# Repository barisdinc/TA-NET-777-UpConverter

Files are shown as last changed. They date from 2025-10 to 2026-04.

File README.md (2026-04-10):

# TA-NET-777-UpConverter
Bu proje yeniden ATOLYE grubu tarafindan TA-NET 777 katilimcilari icin hazirlanmis bir 2.4 GHz Upconverter projesidir.
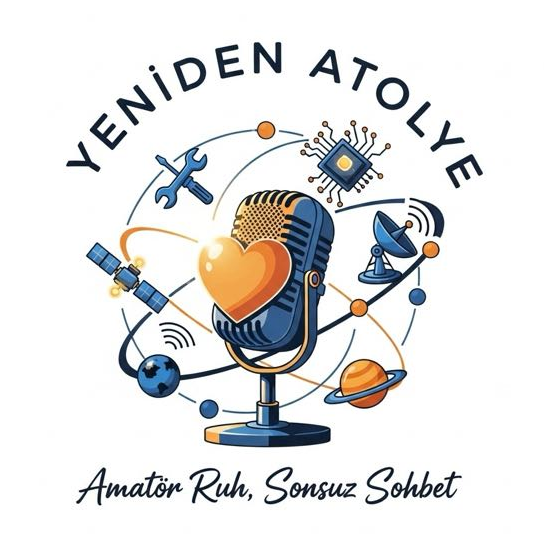
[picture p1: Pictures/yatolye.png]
yenidenATOLYE

Proje hakkinda detayli bilgiler icin asagidaki video ve sunumu izlemenizi oneririz :
- https://youtu.be/WVTPuhvnB4w
- https://youtu.be/KhWMfrUOU8w
- https://youtu.be/caV9FkoR3bo
- https://youtu.be/nuQJzcfvQ-c

Playlist 
- https://www.youtube.com/playlist?list=PLecaGE98mtkhjbvLQakkzYl7DVgV7Ta73

Genel Ozellikleri :
- HF/VHF/UHF cihazlari kullanarak (SSB) QO-100 uyudusuna upconvert yapmak icin kullanilir
- 28/50/144/435 MHz girisinden 2.4 GHz'e upconvert islemini yapar.
- secimi uzerinde bulunan 2 adet dipswitch ile yapilmaktadir
- 28 Mhz yerine opsiyonel olarak 1200 MHz kullanabilrisiniz, kod icinde gerekli duzenlemeler ile ilgili aciklamalar mevcuttur
- Maksimum giris gucu 5 Watt i asmamalidir
- cihazin cikis gucu (SKY ile ) 1 watt civasindandir ve EDUP benzeri anfiler ile daha yuksek guclere cikilabilir
- SKY kullanilmadigi durumda 100-200 Miliwat civarinda bir guc ile istediginiz bir anfi ile kullanabilirisiniz

- Konu hakkinda detayli bir yaziyi da asagidaki sayfada bulabilirsiniz :

https://ta1d.com/qo100-up-converter-ta777-yeni-atolye-grup-calismasi/

Sema, GERBER ve PCB detaylarini (ve BOM ) bilgilerini dokumanlar dizininde bulabilirsiniz.
Kodu nasil derleyeceginiz (arduinino ya da avr-gcc ile) kodun bas kisminda mevcuttur.
Hazir derlenmis HEX dosyalari da yukaridaki klasorlerde mevcuttur

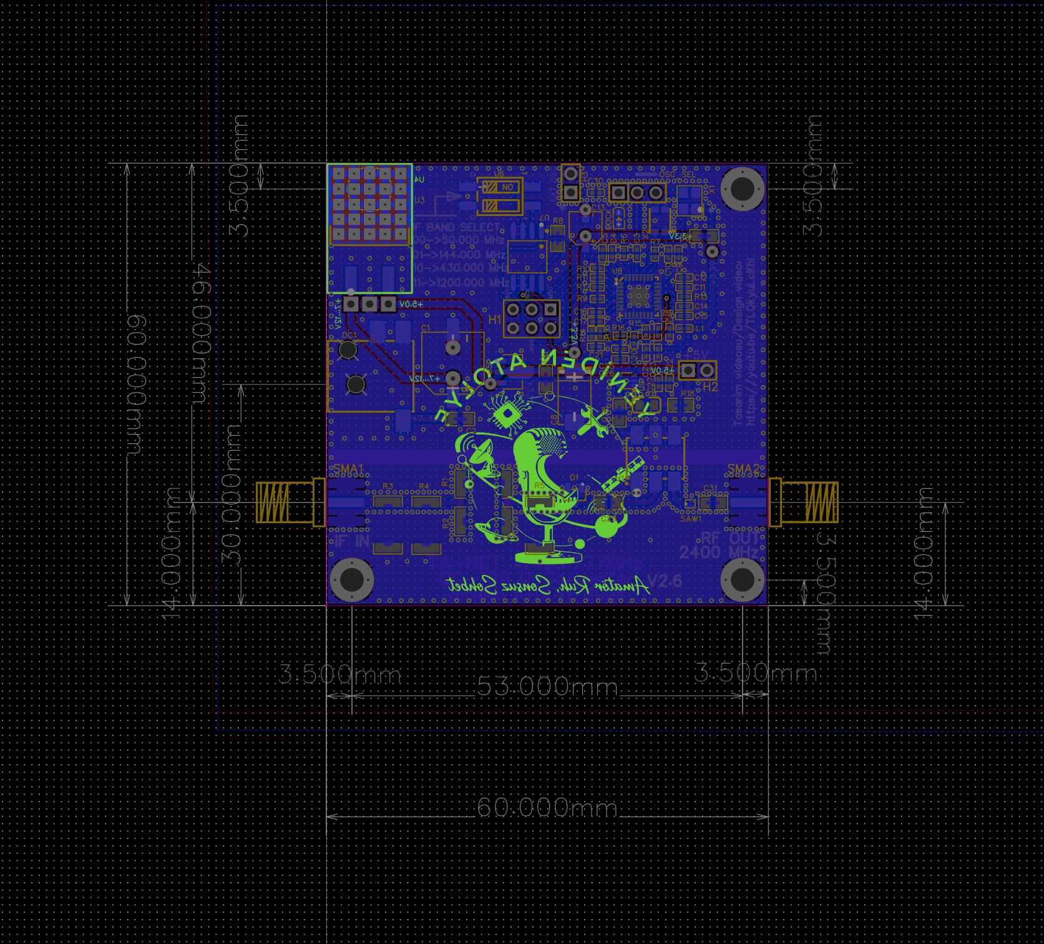
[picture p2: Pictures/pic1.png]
sizes

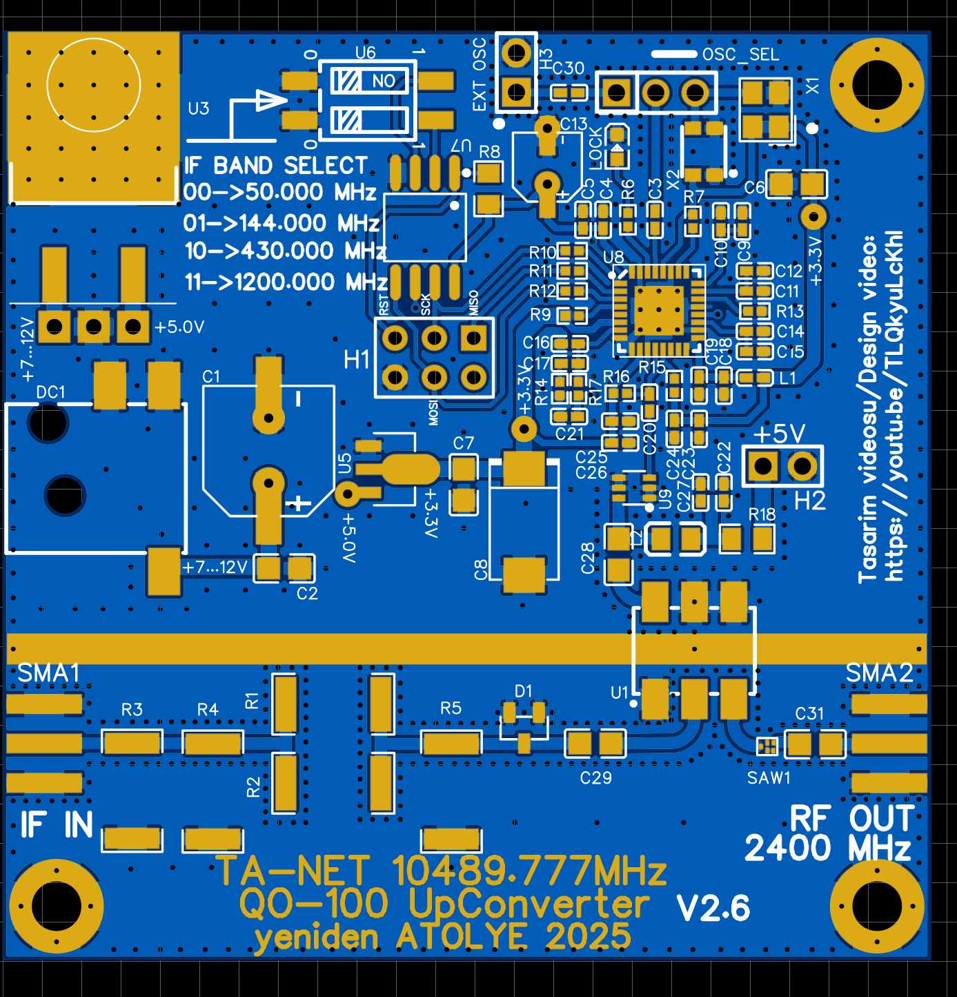
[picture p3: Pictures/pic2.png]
2D View

2D Gorunum
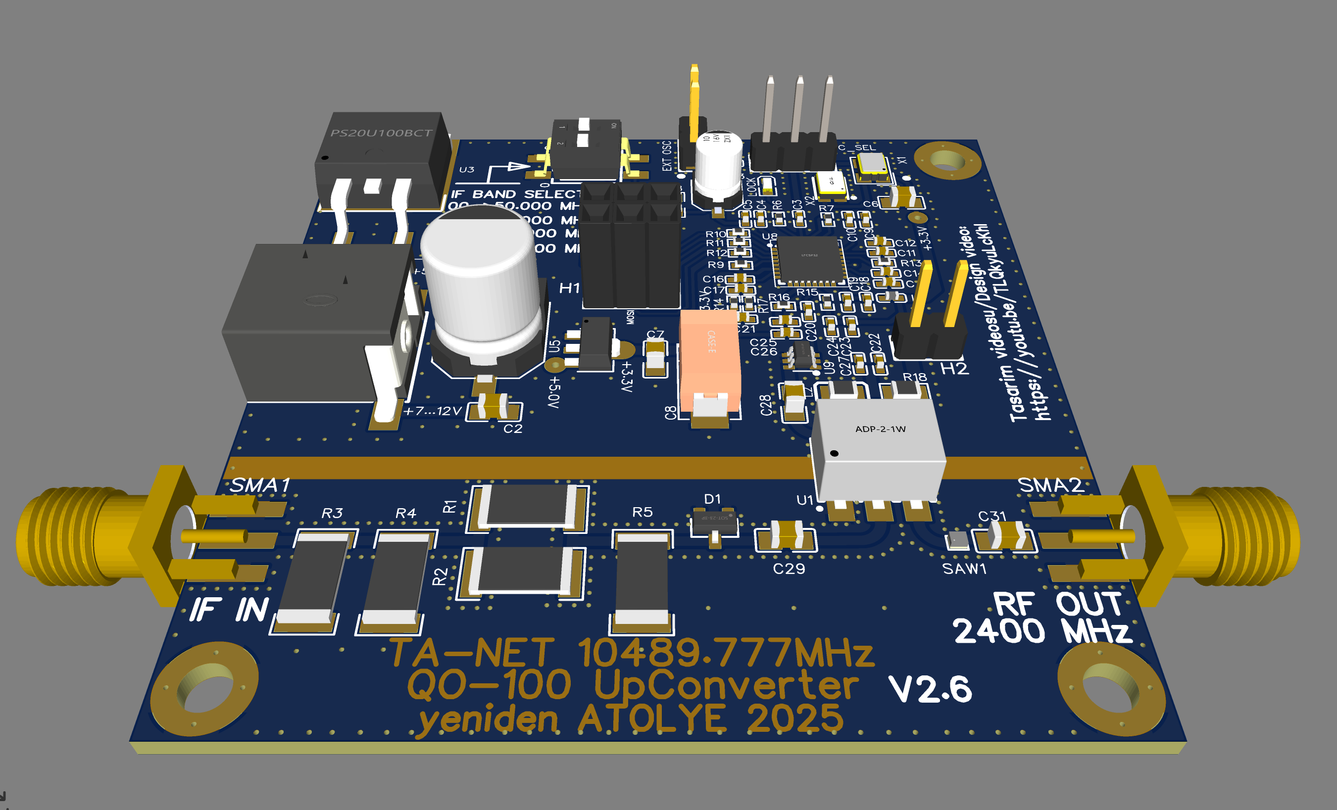
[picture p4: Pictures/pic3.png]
3D View - Front

3D Gorunum (On)
3D View Back
3D Gorunum (arka)
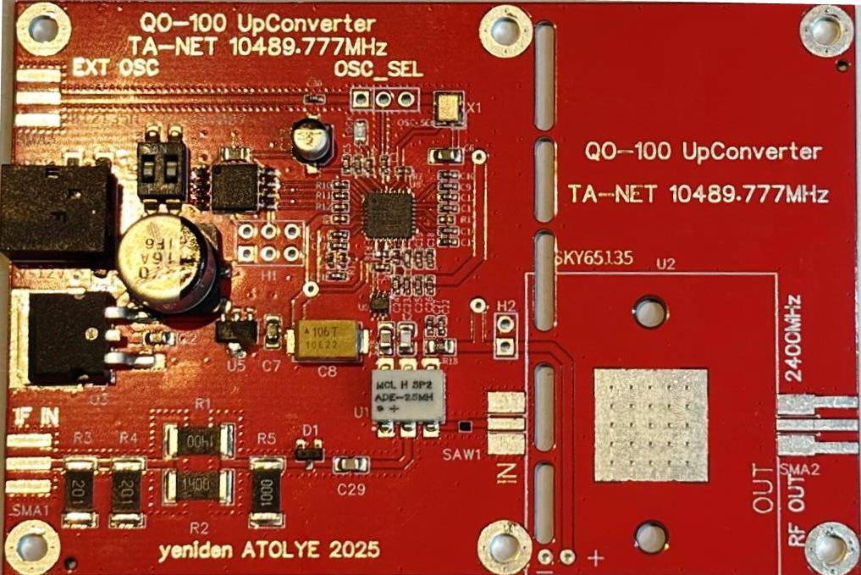
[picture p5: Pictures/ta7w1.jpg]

Prototip Gorunumu 1
Prototypes
Prototip Gorunumu 2
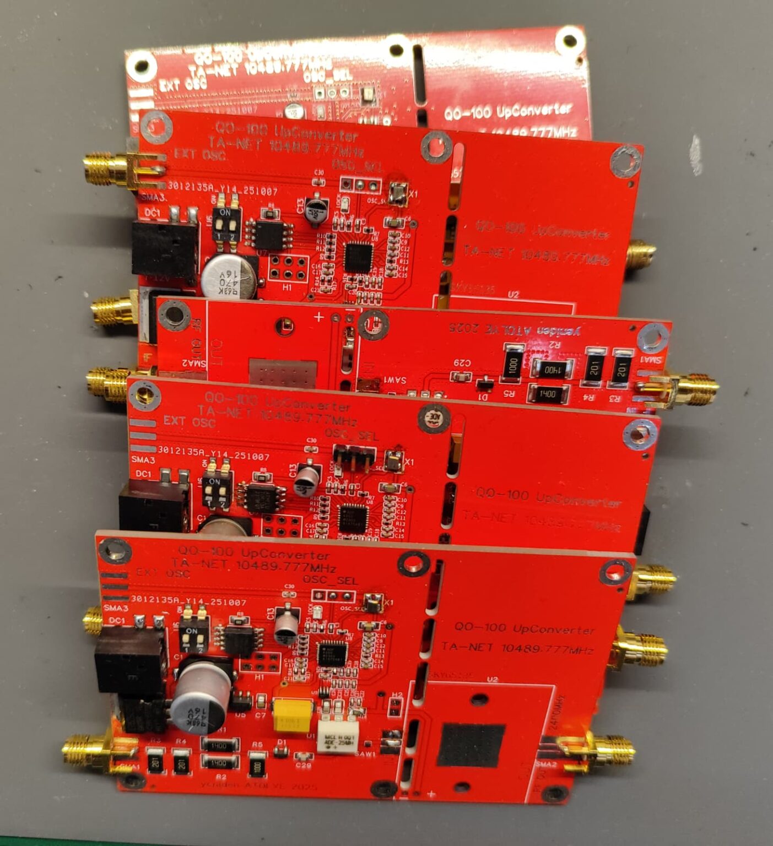
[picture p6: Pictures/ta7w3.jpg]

Prototip Gorunumu 3
Prototypes
Prototip Gorunumu 4
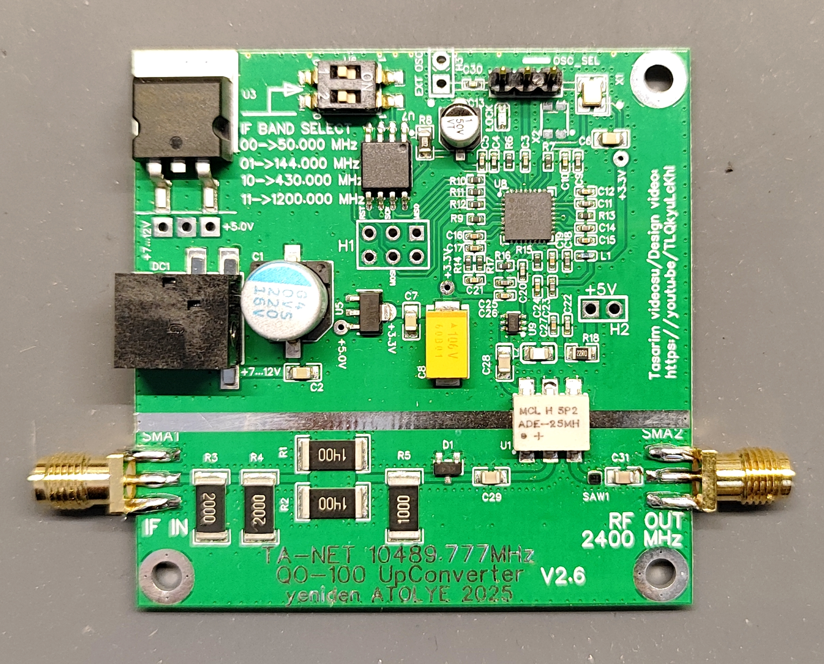
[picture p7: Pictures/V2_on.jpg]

V2 Versiyon On Yuz
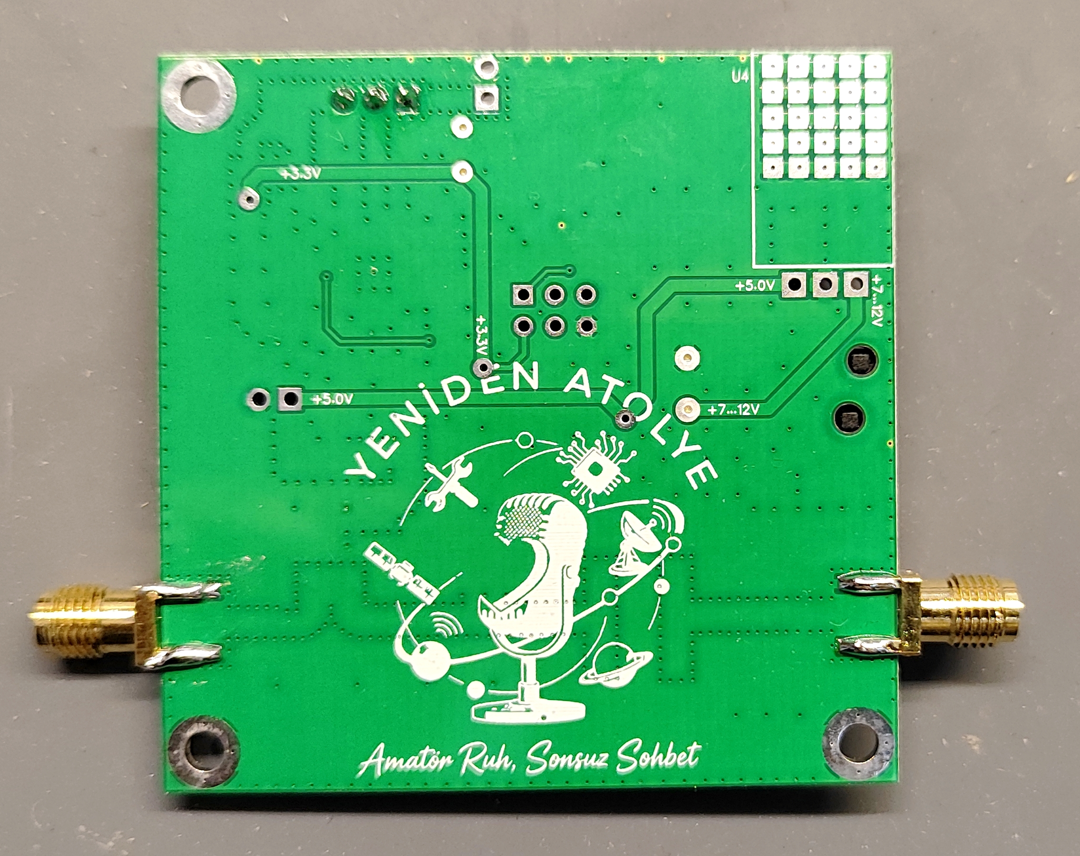
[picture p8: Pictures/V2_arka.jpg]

V2 Versiyon Arka Yuz
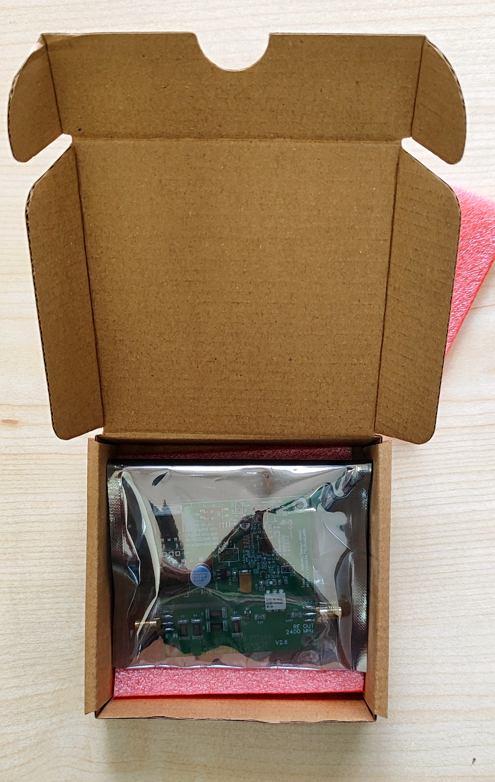
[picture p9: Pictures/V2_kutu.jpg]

V2 Versiyon Kutulanmis

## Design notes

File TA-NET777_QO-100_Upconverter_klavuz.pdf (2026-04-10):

# ATÖLYE ÇALIŞMA GRUBU

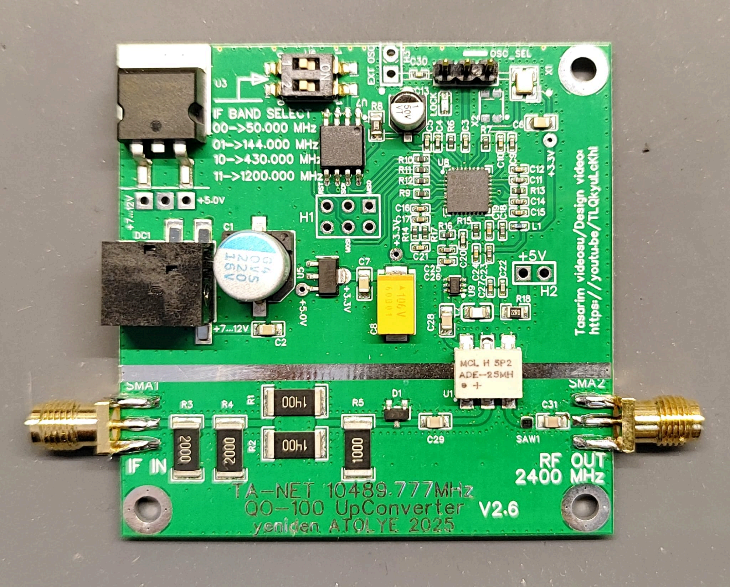
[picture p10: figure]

# QO-100 / 2400 MHz UpConverter Kiti

# Açıklama Dokümanı

# Projenin Amacı

Atölye grubu radyo amatörlüğü konularında araştırma ve geliştirme faaliyetleri gösteren küçük

bir amatör topluluktur. Grup, elektronik ve teknik konularda araştırma faaliyetlerini videolar,

dokümanlar, çalışma grupları ve hazırladıkları kitler aracılığı ile diğer radyo amatörleri ile de

paylaşmayı hedeflemiştir.

Atölye çalışma grubu tarafından tasarlanan ve imal edilen “TA-NET 777 QO-100 Upconverter”

devresinin amacı, öncelikle ülkemizdeki QO-100 uydusu kullanımını yaygınlaştırmak ve SHF

(Super High Frequency) yüksek frekans kullanımı konusunda kullanıcı farkındalığını arttırarak

mikrodalga haberleşmesine olan ilgiyi arttırmaktır.

Bu kapsamda 2025 yılı faaliyetleri kapsamında aşağıda detayları açıklanan HF, VHF, UHF ve

SHF frekanslarından (28MHz, 145MHz, 435MHz ve 1250 MHz) özellikle QO-100 uydusunun

uplink frekansı olarak kullanılan 13cm (2400 MHz) bandına yükseltilmesini sağlayacak bir proje

gerçekleştirilmiş, projenin tasarım çalışmaları ve konu ile ilgili anlatımlı sunumlar

https://www.youtube.com/playlist?list=PLecaGE98mtkhjbvLQakkzYl7DVgV7Ta73 Adresinde

bulunan youtube videosu ile paylaşılmıştır.

# Upconverter için nasıl bir sisteme sahip olmalıyım ?

Upconverter kullanabilmek için, elinizde giriş frekanslarından herhangi birinde çalışan bir SSB

telsiz ihtiyacınız vardır, örneğin :

- VHF SSB (ICOM IC-705, ICOM IC-706, YAESU FT-817, YAESU FT857, vb.)
- UHF SSB (ICOM IC-705, ICOM IC-706, YAESU FT-817, YAESU FT857, vb.)
- SHF SSB (ICOM IC-9700, KENWOOD TS-2000X, vb.)
- 50 MHz (ICOM HF, YAESU HF cihazlar ve QMX+ )

# Sistemin genel blok şeması nasıldır ?

Anten bileşeni dahil sistemin alt bileşenlerinin gösterildiği blok şema yapısı aşağıdaki gibidir :

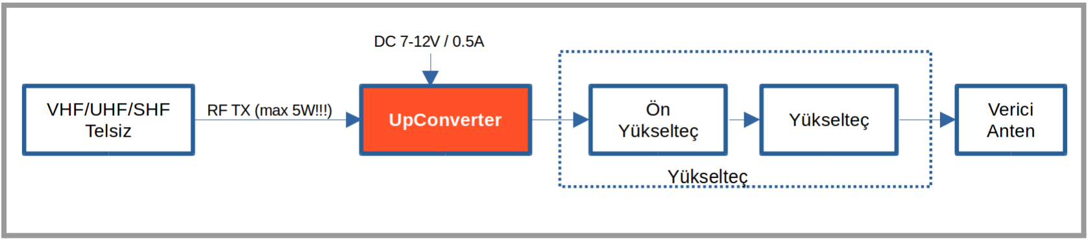
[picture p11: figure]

Şekil 1 - Sistemin Blok Şeması

# Sistemin detay şeması

Sistemin elektronik şema çizimi aşağıdaki gibidir. Bu şema EasyEda yazılımı kullanılarak

hazırlanmış olup, hazırlanma aşaması ve bu aşamada verilen tüm kararar yukarıda paylaşılan

video linkinde bulunan videolardan detaylıca takip edilebilir. Her kullanıcı olmasa da radyo

amatörlüğünün teknik ve elektronik alanına ilgi duyanların bu videoları izleyerek farklı frekanslar

için tasarlanabilecek updonverter/downconverter çalışmalarına destek olacağını düşünüyoruz.

Videolarda sadece bir upconverter/downconverter tasarımı konusu değil temel elektronik

tasarımı esnasında izlenen adımlar detaylıca anlatılmaya çalışılmış ve bu çalışmanın bir eğitim

içeriği olmasına özen gösterilmeye çalışılmıştır.

Şema 2 bölümden oluşmaktadır :

- Üst seviye şematik
- Osilatör ve Mixer

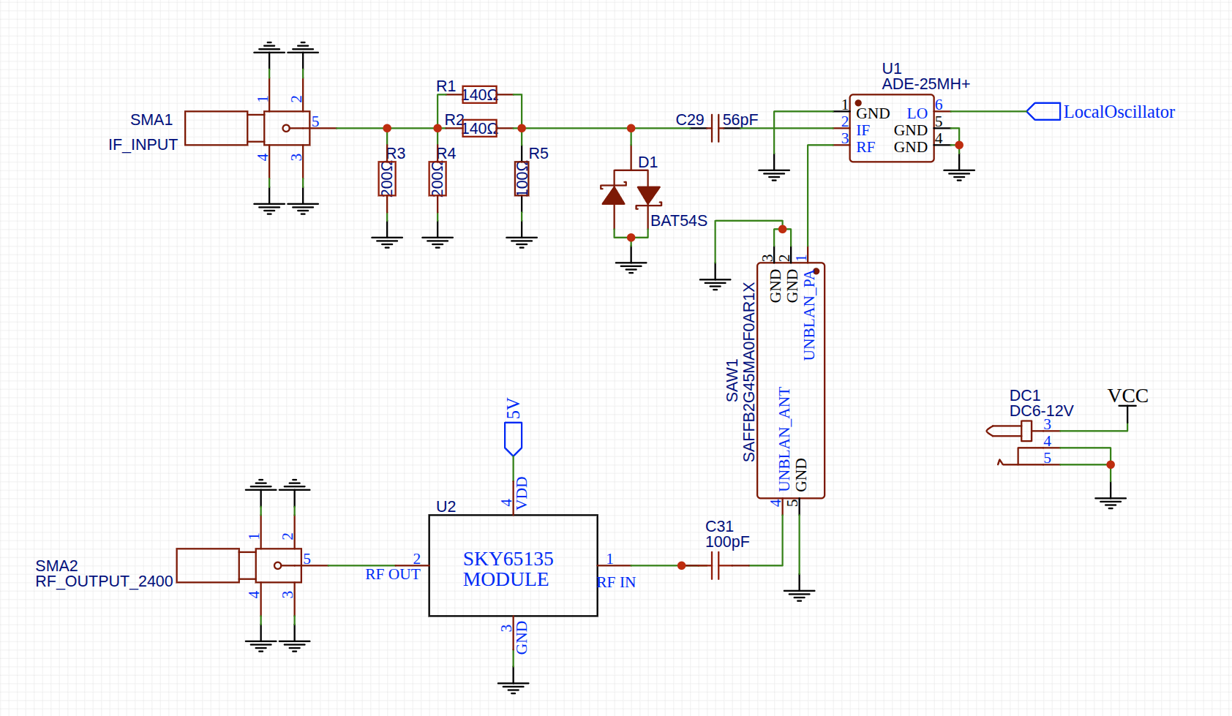
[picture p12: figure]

Şekil 2 - Üst Seviye Şematik

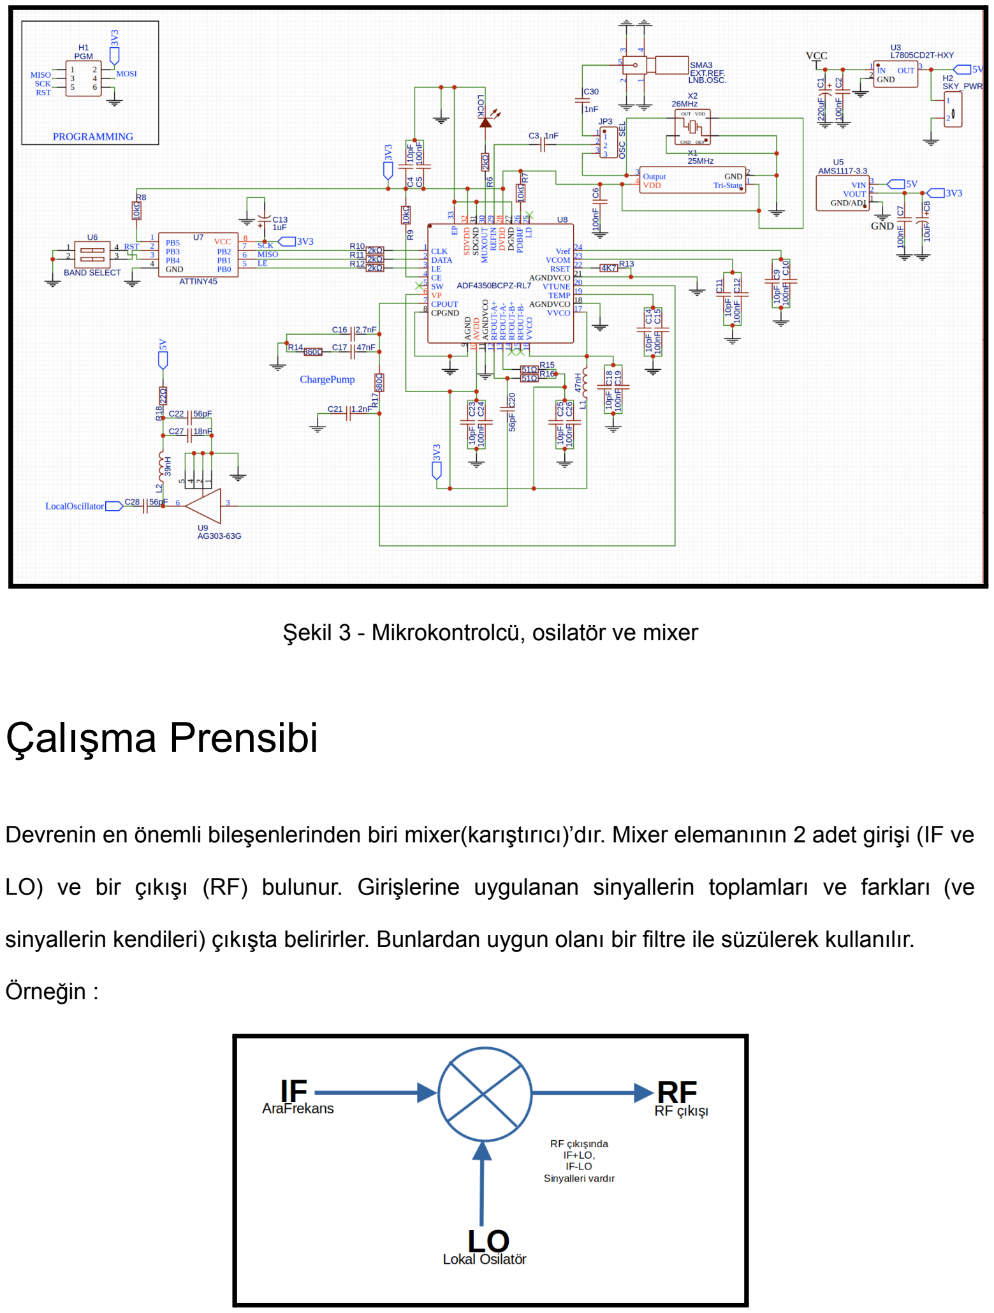
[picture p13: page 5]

Şekil 3 - Mikrokontrolcü, osilatör ve mixer

# Çalışma Prensibi

Devrenin en önemli bileşenlerinden biri mixer(karıştırıcı)’dır. Mixer elemanının 2 adet girişi (IF ve

LO) ve bir çıkışı (RF) bulunur. Girişlerine uygulanan sinyallerin toplamları ve farkları (ve

sinyallerin kendileri) çıkışta belirirler. Bunlardan uygun olanı bir filtre ile süzülerek kullanılır.

Örneğin :

Devrede ATTiny mikroişlemcisi tarafından yönetilen ADF4350/ADF4351 frekans sentözörü Lokal

Osilatör sinyali olarak kullanılak olan RF sinyalini üretir.

Bu frekans kullanılacak IF telsiz girişi frekansı ile uygun olarak aşağıdaki frekansları

üretmektedir;

- VHF telsiz için 2400 - 145 = 2255MHz
- UHF Telsiz için 2400 - 435 = 1965 Mhz
- 50 Mhz bandı için 2400 - 50 = 2350 MHz
- 1250 MHz için 2400 - 1250 = 1150 MHz

Böylece telsizden gelen sinyal ile lokal osilatörde üretilen sinyal kullanılan ADE-25MH

mikserinde karıştırıldığında çıkışında 2400 Mhz oluşur. Bu sinyal diğer bileşenlerden kurtulmak

için bir filtre ile temizlenir.

# Devre üzerindeki malzeme listesi

Devre üzerinde yer alan malzemelerin listesi aşağıda verilmiştir :

| Değeri | Malzeme Kodu | Boyutu | Üretici Numarası
1 | 220uF | C1 | CAP-SMD_BD8.0-L8.3-W8. 3-LS9.3-FD | 126RV0174
2 | 100nF | C2,C6,C7 | C0805 | CC0805KRX7R7BB104
3 | 1nF | C3,C30 | C0402 | CL21B102KBANNNC
4 | 10pF | C4,C9,C11,C14,C18,C23 ,C25 | C0402 | 0805CG100J101NT

5 | 100nF | C5,C10,C12,C15,C19,C2 4,C26 | C0402 | CC0805KRX7R7BB104
6 | 10uF | C8 | CAP-SMD_L7.3-W4.3-FD | TAJE106M050RNJ
7 | 1uF | C13 | CAP-SMD_BD4.0-L4.3-W4. 3-LS5.3-FD | VT105M050C5DRR0N B1VP0
8 | 2.7nF | C16 | C0402 | GRM2165C1H272JA01 D
9 | 47nF | C17 | C0402 | 0805B473K500NT
10 | 56pF | C20,C22 | C0402 | 0805CG560J500NT
11 | 1.2nF | C21 | C0402 | NL0805B122K500CPB N
12 | 18nF | C27 | C0402 | 0805F183M500NT
13 | 56pF | C28,C29 | C0805 | 0805CG560J500NT
14 | 100pF | C31 | C0402 | AM02CG101J500NT
15 | BAT54S | D1 | SOT-23-3_L2.9-W1.3-P1.90 -LS2.4-BR | BAT54S
16 | DC6-12V | DC1 | DC-IN-SMD_DC-044D-2.5A -2.0-SMT | DC-044D-2.5A-2.0-SMT
17 | SKY_PWR | H2 | HDR-TH_2P-P2.54-V-M-1 | 826629-2
18 | 47nH | L1 | L0402 | VHF201209H47NJT

19 | 39nH | L2 | L0805 | VHF201209H39NJT
20 | NCD0603R 6 | LOCK | LED0603-RD | NCD0603R6
21 | 140Ω | R1,R2 | R2512 | 25121WF1400T4E
22 | 200Ω | R3,R4 | R2512 | HP122WF2000T4E
23 | 100Ω | R5 | R2512 | 25121WF1000T4E
24 | 2kΩ | R6,R10,R11,R12 | R0402 | RS-05K2001FT
25 | 10kΩ | R7,R9 | R0402 | FRH0805B1002TS
26 | 10kΩ | R8 | R0805 | FRH0805B1002TS
27 | 4K7 | R13 | R0402 | RC0805FR-074K7L
28 | 360Ω | R14 | R0402 | RC0805FR-07360RL
29 | 51Ω | R15,R16 | R0402 | RC0805FR-0751RL
30 | 680Ω | R17 | R0402 | FRC0805J681 TS
31 | 22Ω | R18 | R0805 | RC0805JR-0722RL
32 | SAFFB2G4 5 | SAW1 | FILTER-SMD_5P-L1.1-W0.9 -L_RSFP2413E | SAFFB2G45MA0F0AR 1X
33 | ADE-25MH + | U1 | SMD-6_L7.8-W5.6-P2.54-L S6.9-BL | ADE-25MH+
34 | L7805CD2T -HXY | U3 | TO-263-2_L10.2-W8.5-P2.5 4-LS15.2-TL | L7805CD2T-HXY

35 | AMS1117-3. 3 | U5 | SOT-89-3_L4.5-W2.4-P1.50 -LS4.0-BR | AMS1117-3.3S
36 | BAND SELECT | U6 | SW-SMD_SMXS-02K-TP | SMXS-02K-TP
37 | ATTINY45 | U7 | SOIC-8_L5.3-W5.3-P1.27-L S8.0-BL | ATTINY45-20PU
38 | ADF4350 | U8 | LFCSP-32_L5.0-W5.0-P0.5 0-TL-EP3.1 | ADF4350BCPZ-RL7
39 | AG303-63G | U9 | SOT-363_L2.0-W1.3-P0.65-LS2.1-BL | AG303-63G
40 | 25MHz | X1 | OSC-SMD_4P-L3.2-W2.5-B L-OXETDLJANF-0.032768M HZ | OXETDLJANF-25MHZ
41 | 26MHz | X2 | OSC-SMD_4P-L3.2-W2.5-B L_1XTV | 1XTW26000MAA

Bağlantı nasıl Yapılır :

- IF IN yazan kısmı maksimum 5 Watt (DİKKAT!!!) olan bir SSB VHF/UHF/SHF telsize

bağlanır

- RF Out kısmı uygun yükselticiler ile antene bağlanır
- DC girişine 7-12V DC uygulanır (dikkat anten yokken enerjilendirmeyiniz)
- SSB BAND select telsizinize uygun olan banda ayarlanır

- Telsiz ile gönderme yaptığınızda upconverter 2400 MHz bandında sinyalinizi uygun

(karşılık gelen) frekanstan gönderecektir. Örneğin : 435.277 MHz’den yapılan yayın

2400.277 MHz’den gönderilir.

# Sistemin Görünüşü

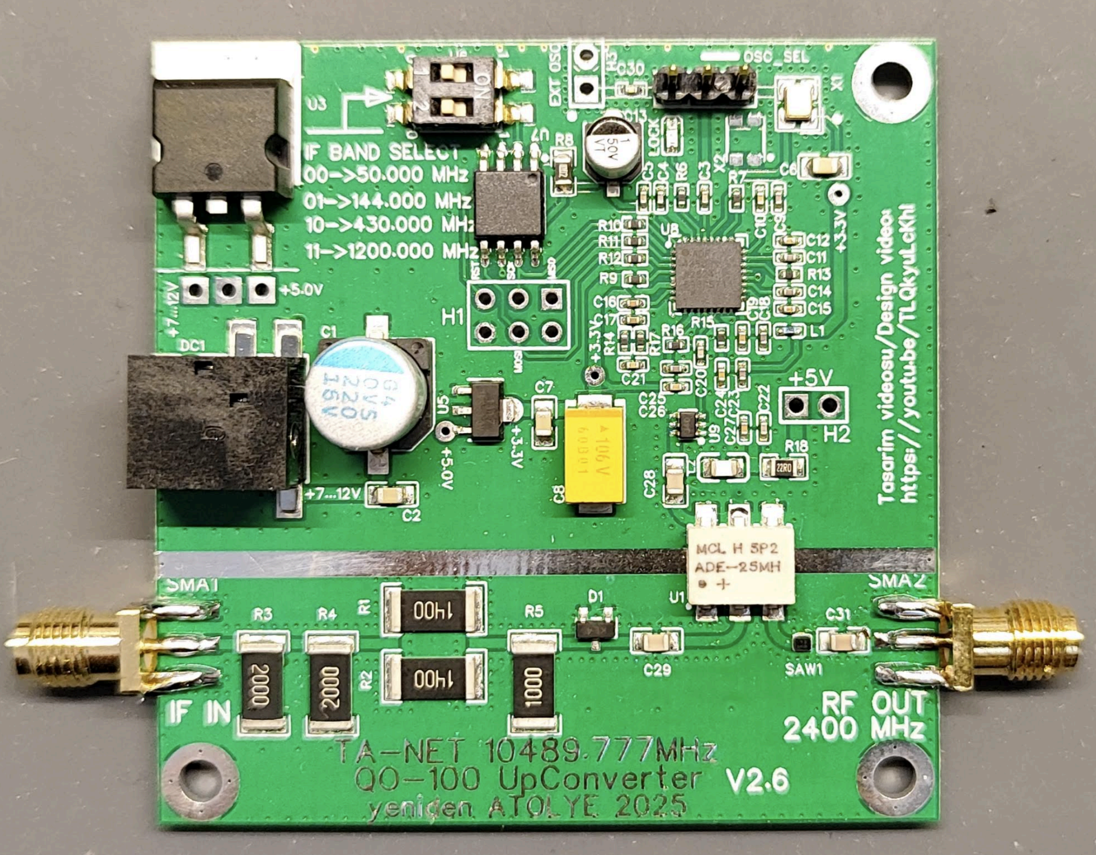
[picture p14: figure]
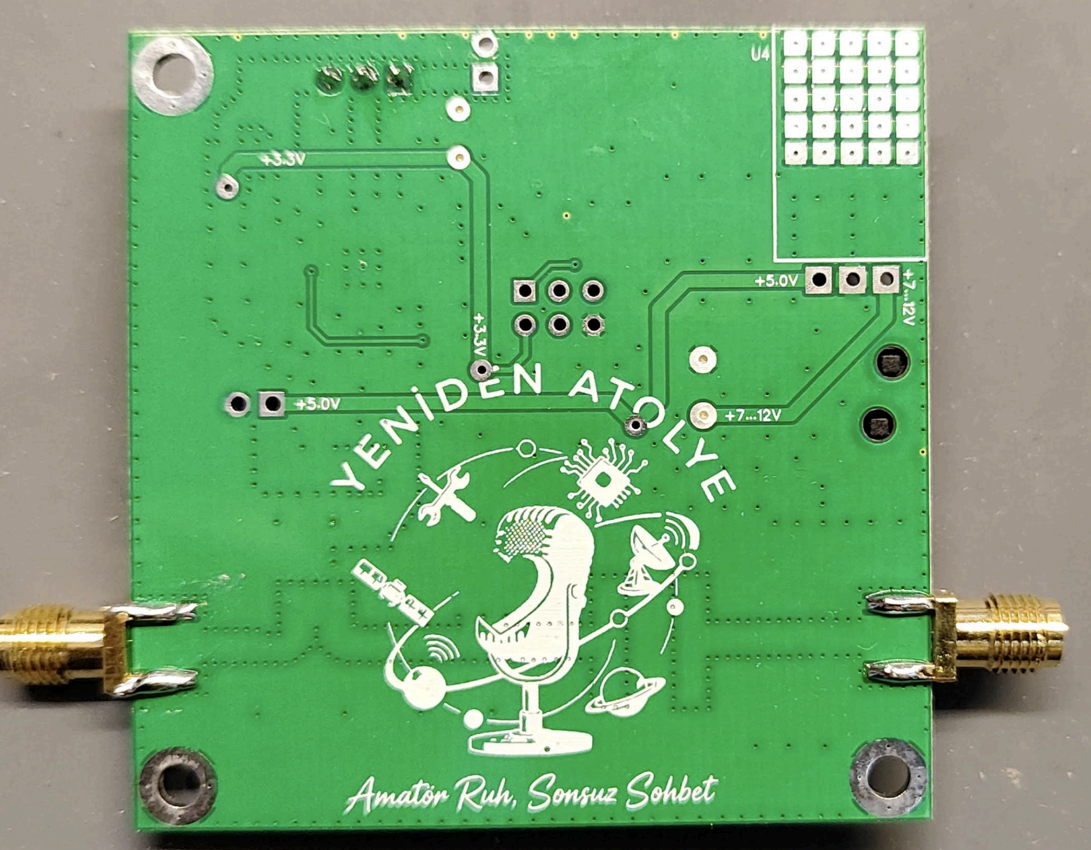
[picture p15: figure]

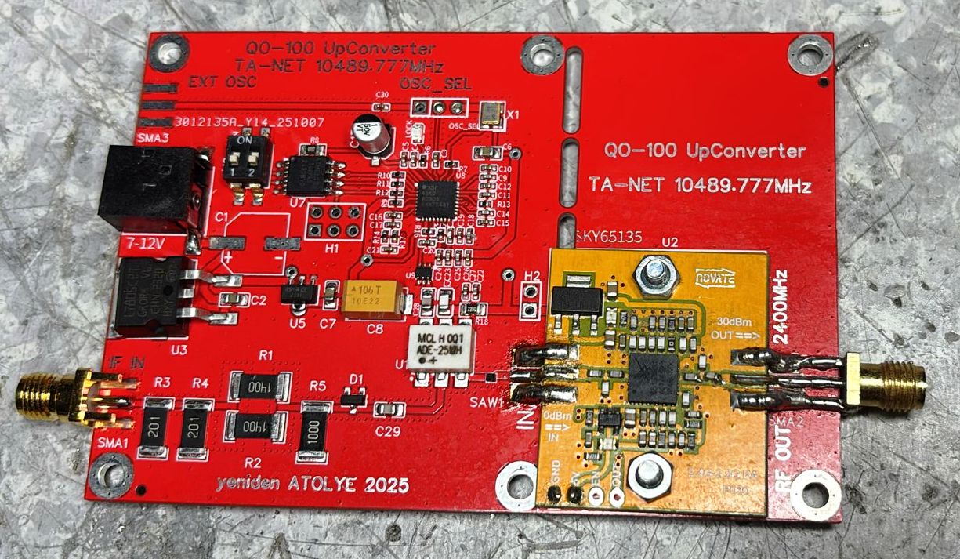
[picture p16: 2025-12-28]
Pictures/ta7w2.jpg

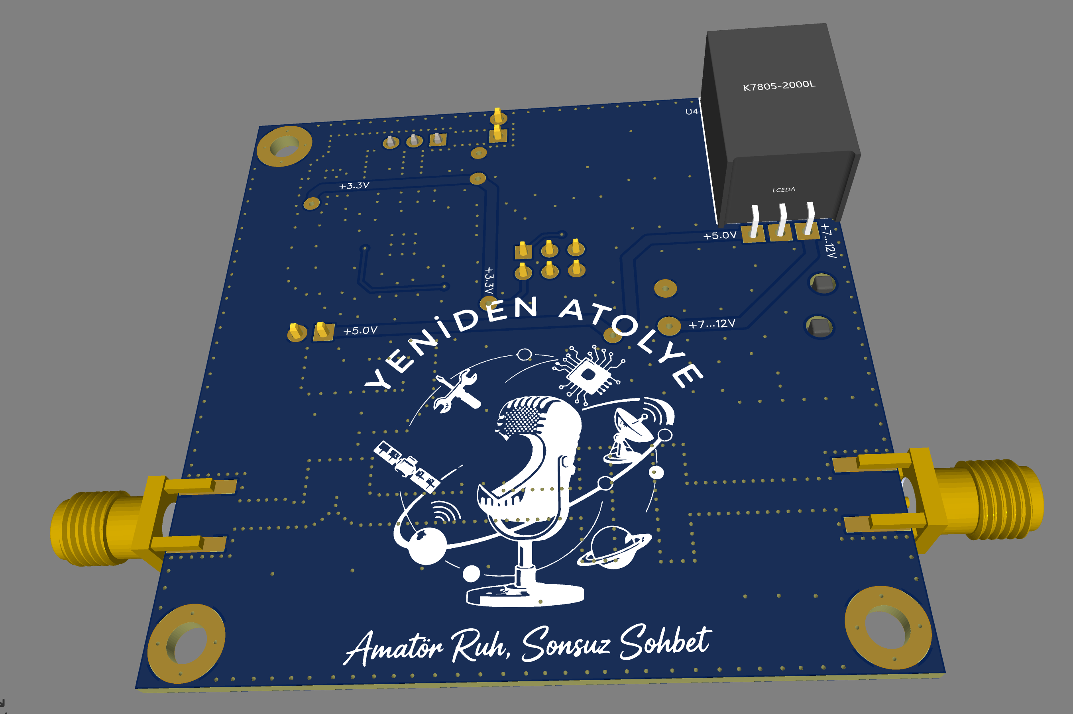
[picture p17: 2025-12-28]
Pictures/pic4.png

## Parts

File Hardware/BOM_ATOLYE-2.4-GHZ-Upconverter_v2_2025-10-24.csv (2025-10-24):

ID | Name | Designator | Footprint | Quantity | Manufacturer Part | Manufacturer | Supplier | Supplier Part | Price
1 | 25MHz | X1 | OSC-SMD_4P-L3.2-W2.5-BL-OXETDLJANF-0.032768MHZ | 1 | OXETDLJANF-25MHZ | TAITIEN(泰艺电子) | LCSC | C5382666 | 0.58
2 | 220uF | C1 | CAP-SMD_BD8.0-L8.3-W8.3-LS9.3-FD | 1 | 126RV0174 | KNSCHA(科尼盛) | LCSC | C7461305 | 0.062
3 | 100nF | C2,C6,C7 | C0805 | 3 | CC0805KRX7R7BB104 | YAGEO(国巨) | LCSC | C519980 | 0.006
4 | BAT54S | D1 | SOT-23-3_L2.9-W1.3-P1.90-LS2.4-BR | 1 | BAT54S | BORN(伯恩半导体) | LCSC | C266597 | 0.016
5 | DC6-12V | DC1 | DC-IN-SMD_DC-044D-2.5A-2.0-SMT | 1 | DC-044D-2.5A-2.0-SMT | XKB Connection(中国星坤) | LCSC | C397342 | 0.162
6 | 140Ω | R2,R1 | R2512 | 2 | 25121WF1400T4E | UNI-ROYAL(厚声) | LCSC | C406961 | 0.027
7 | 200Ω | R3,R4 | R2512 | 2 | HP122WF2000T4E | UNI-ROYAL(厚声) | LCSC | C2765767 | 0.056
8 | 100Ω | R5 | R2512 | 1 | 25121WF1000T4E | UNI-ROYAL(厚声) | LCSC | C35218 | 0.024
9 | SAFFB2G45MA0F0AR1X | SAW1 | FILTER-SMD_5P-L1.1-W0.9-L_RSFP2413E | 1 | SAFFB2G45MA0F0AR1X | muRata(村田) | LCSC | C910680 | 0.123
10 | ADE-25MH+ | U1 | SMD-6_L7.8-W5.6-P2.54-LS6.9-BL | 1 | ADE-25MH+ | Mini-Circuits | LCSC | C879849 | 8.199
11 | 10uF | C8 | CAP-SMD_L7.3-W4.3-FD | 1 | TAJE106M050RNJ | Kyocera AVX | LCSC | C5348217 | 1.748
12 | 1uF | C13 | CAP-SMD_BD4.0-L4.3-W4.3-LS5.3-FD | 1 | VT105M050C5DRR0NB1VP0 | Chengx(承兴) | LCSC | C3039816 | 0.026
13 | 56pF | C28,C29 | C0805 | 2 | 0805CG560J500NT | FH(风华) | LCSC | C1828 | 0.005
14 | 39nH | L2 | L0805 | 1 | VHF201209H39NJT | FH(风华) | LCSC | C98994 | 0.011
15 | 10kΩ | R8 | R0805 | 1 | FRH0805B1002TS | FOJAN(富捷) | LCSC | C17414 | 0.002
16 | 22Ω | R18 | R0805 | 1 | RC0805JR-0722RL | YAGEO(国巨) | LCSC | C108406 | 0.002
17 | L7805CD2T-HXY | U3 | TO-263-2_L10.2-W8.5-P2.54-LS15.2-TL | 1 | L7805CD2T-HXY | HXY MOSFET(华轩阳电子) | LCSC | C7469133 | 0.281
18 | AMS1117-3.3 | U5 | SOT-89-3_L4.5-W2.4-P1.50-LS4.0-BR | 1 | AMS1117-3.3S | TECH PUBLIC(台舟) | LCSC | C46473005 | 0.044
19 | BAND SELECT | U6 | SW-SMD_SMXS-02K-TP | 1 | SMXS-02K-TP | SM Switch | LCSC | C5439761 | 0.407
20 | ATTINY45 | U7 | SOIC-8_L5.3-W5.3-P1.27-LS8.0-BL | 1 | ATTINY45-20PU | MICROCHIP(美国微芯) | LCSC | C152181 | 2.677
21 | ADF4350BCPZ-RL7 | U8 | LFCSP-32_L5.0-W5.0-P0.50-TL-EP3.1 | 1 | ADF4350BCPZ-RL7 | ADI(亚德诺) | LCSC | C98705 | 8.016
22 | AG303-63G | U9 | SOT-363_L2.0-W1.3-P0.65-LS2.1-BL | 1 | AG303-63G | Qorvo | LCSC | C469031 | 0.888
23 | 4K7 | R13 | R0402 | 1 | RC0805FR-074K7L | YAGEO(国巨) | LCSC | C60816 | 0.002
24 | 10pF | C9,C11,C14,C18,C23,C25,C4 | C0402 | 7 | 0805CG100J101NT | FH(风华) | LCSC | C179756 | 0.007
25 | 100nF | C10,C19,C12,C15,C24,C26,C5 | C0402 | 7 | CC0805KRX7R7BB104 | YAGEO(国巨) | LCSC | C519980 | 0.006
26 | 47nH | L1 | L0402 | 1 | VHF201209H47NJT | FH(风华) | LCSC | C46431 | 0.011
27 | 56pF | C20,C22 | C0402 | 2 | 0805CG560J500NT | FH(风华) | LCSC | C1828 | 0.005
28 | 51Ω | R15,R16 | R0402 | 2 | RC0805FR-0751RL | YAGEO(国巨) | LCSC | C114537 | 0.002
29 | 2kΩ | R10,R11,R12,R6 | R0402 | 4 | RS-05K2001FT | FH(风华) | LCSC | C132365 | 0.002
30 | 2.7nF | C16 | C0402 | 1 | GRM2165C1H272JA01D | muRata(村田) | LCSC | C97900 | 0.026
31 | 47nF | C17 | C0402 | 1 | 0805B473K500NT | FH(风华) | LCSC | C1745 | 0.006
32 | 1.2nF | C21 | C0402 | 1 | NL0805B122K500CPBN | HUI JU(汇聚) | LCSC | C2961024 | 0.008
33 | 360Ω | R14 | R0402 | 1 | RC0805FR-07360RL | YAGEO(国巨) | LCSC | C137538 | 0.002
34 | 680Ω | R17 | R0402 | 1 | FRC0805J681 TS | FOJAN(富捷) | LCSC | C2907340 | 0.001
35 | 1nF | C3,C30 | C0402 | 2 | CL21B102KBANNNC | SAMSUNG(三星) | LCSC | C51210 | 0.008
36 | 10kΩ | R7,R9 | R0402 | 2 | FRH0805B1002TS | FOJAN(富捷) | LCSC | C5159707 | 0.014
37 | NCD0603R6 | LOCK | LED0603-RD | 1 | NCD0603R6 | 国星光电 | LCSC | C7429910 | 0.007
38 | 18nF | C27 | C0402 | 1 | 0805F183M500NT | FH(风华) | LCSC | C1767 | 0.015

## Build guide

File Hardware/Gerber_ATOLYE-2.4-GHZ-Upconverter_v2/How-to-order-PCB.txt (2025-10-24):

How to Order PCB

Please refer to:
https://docs.easyeda.com/en/PCB/Order-PCB

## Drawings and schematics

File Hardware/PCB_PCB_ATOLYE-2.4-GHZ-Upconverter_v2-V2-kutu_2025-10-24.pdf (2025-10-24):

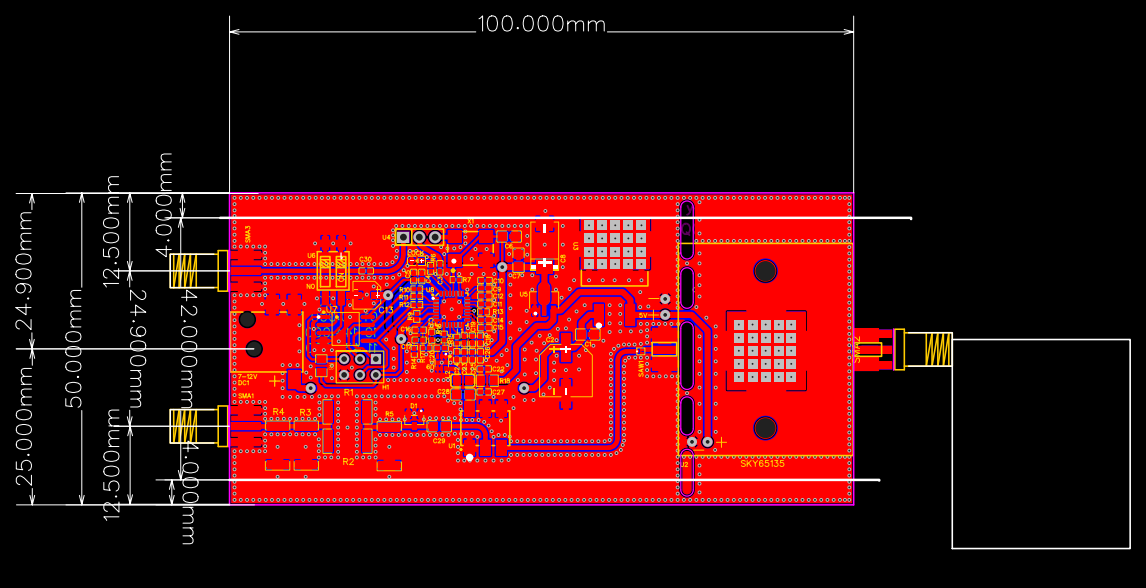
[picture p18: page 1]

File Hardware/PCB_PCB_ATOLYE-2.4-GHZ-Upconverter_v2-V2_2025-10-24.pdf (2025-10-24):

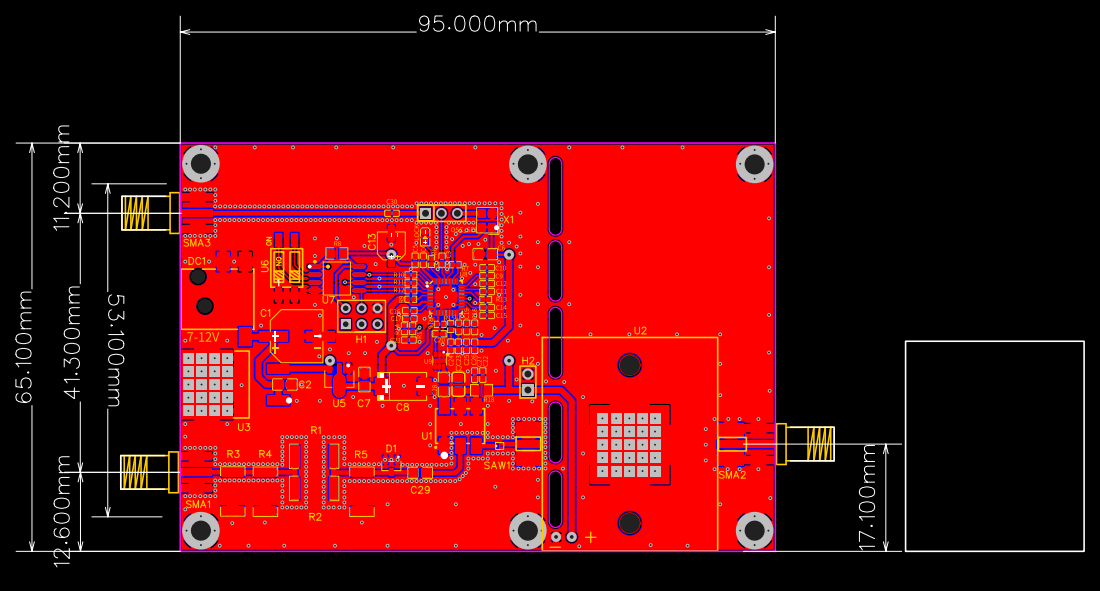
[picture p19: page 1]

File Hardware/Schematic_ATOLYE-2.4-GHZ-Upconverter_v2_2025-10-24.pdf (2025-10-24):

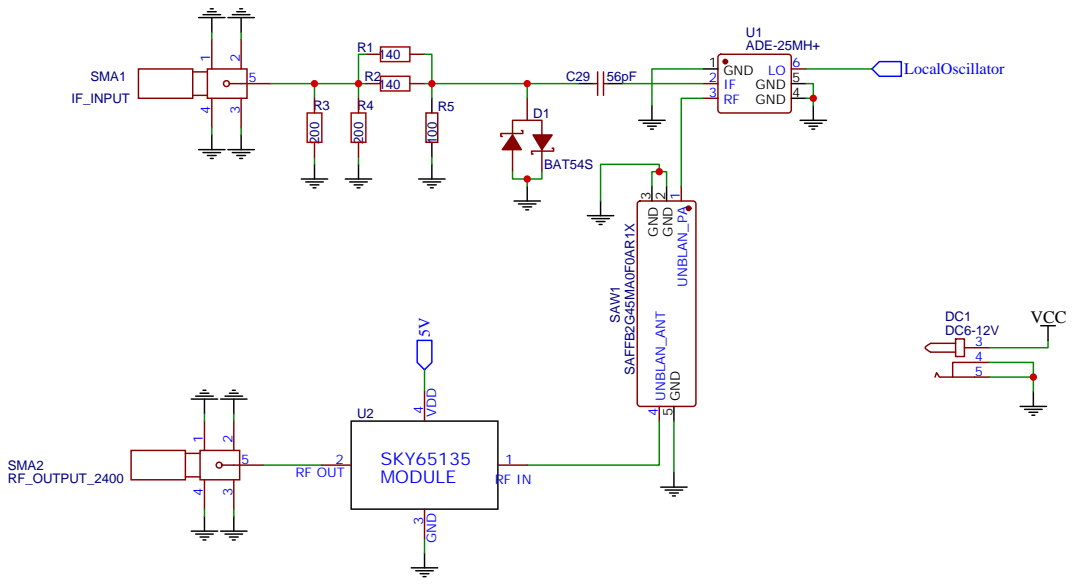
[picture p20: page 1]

Drawn By: Yeniden ATOLYE Group

# VCC220uF C¹

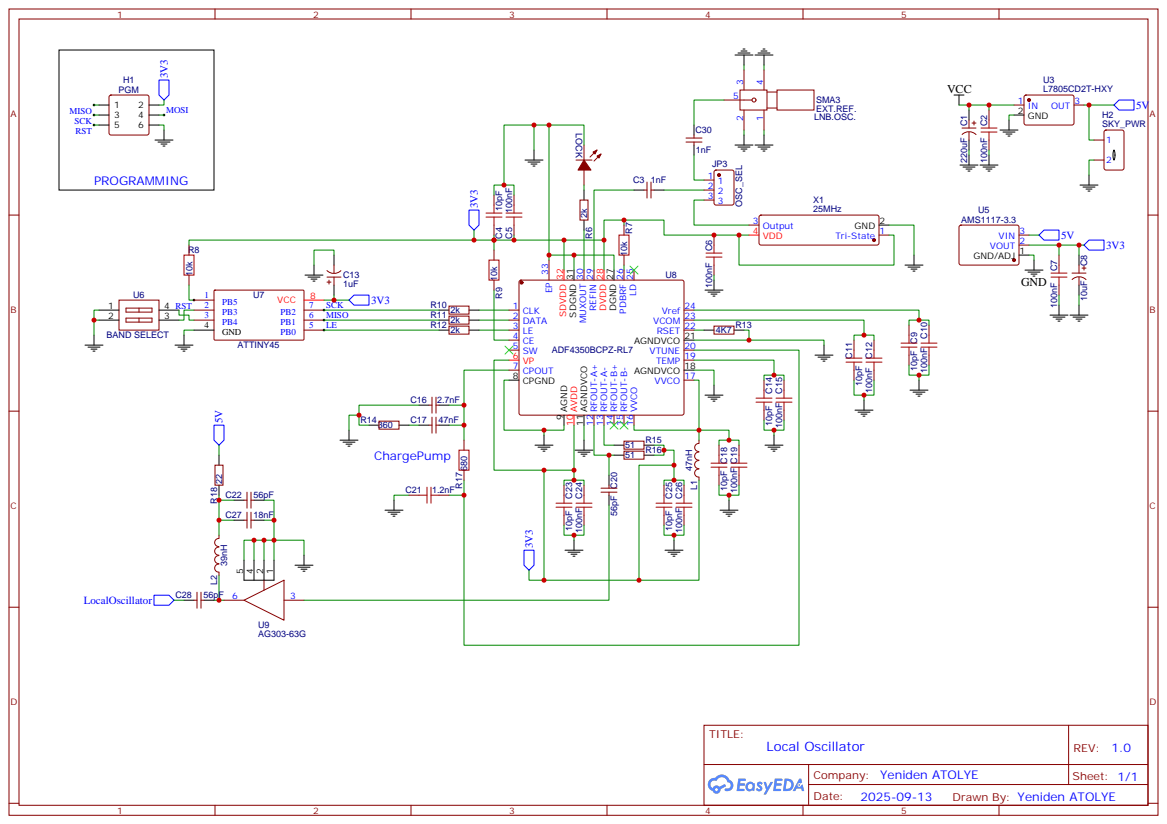
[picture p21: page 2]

Drawn By: Yeniden ATOLYE

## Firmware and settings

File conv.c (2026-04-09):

/*
  yeniden ATOLYE 2025 (CopyLeft)
  QO-100 Upconverter
  
  ISTEK: PB3 ve PB4 girislerini oku, PB0 ve PB1 cikislarina yansit.
  NOT: Bu kod, PB0/PB1'i hem PLL (LE/DATA) hem de durum gostergesi
       olarak kullanir. PLL yazmasi bittikten sonra pinler
       PB3/PB4'un durumunu yansitir.

  derleme :
  avr-gcc -g -Os -mmcu=attiny45 atolye_uc.c -o a.out
  avr-objcopy -O ihex -j.text -j.data a.out atolye_uc.hex
  yazma:
  avrdude -p attiny45 -c avrispmkII -P usb -U flash:w:atolye_uc.hex:i
*/


#define F_CPU 8000000L 

#include <avr/io.h>
#include <util/delay.h>



long int r0, r1, r2, r3, r4, r5;

void write2PLL(uint32_t PLLword) {         // clocks 32 bits word  directly to the ADF4351
                                          // msb (b31) first, lsb (b0) last 
   for (char i=32; i>0; i--) {   // PLL word 32 bits 

     if (PLLword & 0x80000000)
     {
        PORTB |= 0b00000010 ; // PB1 (DATA) = 1
     }
     else
     {
        PORTB &= 0b11111101 ; // PB1 (DATA) = 0
     }
     PORTB |= 0b00000100;                 // clock in bit on rising edge of CLK (PB2 = 1)
     PORTB &= 0b11111011;                // CLK (PB2 = 0) 
     PLLword <<= 1; 
     } 
     PORTB |= 0b00000001;                 // latch in PLL word on rising edge of LE (PB0 = 1)
     PORTB &= 0b11111110;  // LE (PB0 = 0)   
     _delay_ms(1);
} 


int main()
{

     DDRB = 0b11100111; // 3 ve 4. portlar INPUT (select switch) digerleri OUTPUT
     PORTB = 0b00011000; // PB3 ve PB4 icin dahili PULL-UP'lari aktif et

     _delay_ms(100);

     // Switch'ler pull-up'li ve active-low varsayiliyor (basinca 0 olurlar)
     // Ilk durum okumasi (Terslenmis)
     uint8_t sw1 = ((~PINB) & 0b00010000) >> 4; // PB4
     uint8_t sw2 = ((~PINB) & 0b00001000) >> 3; // PB3
     uint8_t sw = sw1 * 2 + sw2;
     uint8_t sw_old = 255; // Ilk dongude guncellemeyi zorla

     while(1)
     {
        //NOT: Kart arkasindaki duruma gore hazirla
        // Switch'leri oku (Terslenmis, 0b00011000 -> 0b00000000)
        
        sw1 = ((~PINB) & 0b00010000) >> 4; // PB4 okuma (active-low)
        sw2 = ((~PINB) & 0b00001000) >> 3; // PB3 okuma (active-low)
        
        sw = sw1 * 2 + sw2; // sw1=MSB, sw2=LSB

        if (sw_old != sw)
        {
           switch (sw)
           {
               case 0:
                   // Fout= 2350 MHz +5dBm LO= 2400 MHz - 50 MHz
                   r0 = 0x2F0000;  
                   r1 = 0x8008011;
                   r2 = 0x18004E42;
                   r3 = 0x4B3;
                   r4 = 0x8C81FC;
                   r5 = 0x580005;
                   break;
               case 1:
                   // Fout= 2256 MHz +5dBm LO= 2400 MHz - 144 MHz
                   r0 = 0x2D0030;  
                   r1 = 0x80080C9;
                   r2 = 0x18004E42;
                   r3 = 0x4B3;
                   r4 = 0x8C81FC;
                   r5 = 0x580005;
                   break;
               case 2:
                   // Fout= 1965 MHz +5dBm LO= 2400 MHz - 435 MHz
                   r0 = 0x4E8008;
                   r1 = 0x8008029;
                   r2 = 0x18004E42;
                   r3 = 0x4B3;
                   r4 = 0x9C81FC;
                   r5 = 0x580005;
                   break;
               //case 3:
               //    // Fout= 1160 MHz +5dBm LO= 2400 MHz - 1240 MHz
               //    r0 = 0x2E0020;  
               //    r1 = 0x8008029;
               //    r2 = 0x18004E42;
               //    r3 = 0x4B3;
               //    r4 = 0x9C81FC;
               //    r5 = 0x580005;
               //    break;
               case 3: //28 MHz icin olan bolumdur
                   // Fout= 2371 MHz +5dBm LO= 2400 MHz - 29 MHz
                   r0 = 0x2F00A8;  
                   r1 = 0x80080C9;
                   r2 = 0x18004E42;
                   r3 = 0x4B3;
                   r4 = 0x8C81FC;
                   r5 = 0x580005;
                   break;

               default:
                   // Fout= 1965 MHz +5dBm LO= 2400 MHz - 435 MHz
                   r0 = 0x4E8008;  
                   r1 = 0x8008029;
                   r2 = 0x18004E42;
                   r3 = 0x4B3;
                   r4 = 0x9C81FC;
                   r5 = 0x580005;
                   break;
           }//case
           
           PORTB &= 0b11111000; 

           write2PLL(r5); 
           write2PLL(r4);
           write2PLL(r3);
           write2PLL(r2);
           write2PLL(r1);
           write2PLL(r0);

           sw_old = sw;
        }//if

        
        
        _delay_ms(10); 
        
     }//while

}

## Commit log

2025-10-24 switch eklendi, compile edilmis hec yuklendi
2025-10-24 fabrication dosyalari
    [BOM_ATOLYE-2.4-GHZ-Upconverter_v2_2025-10-24.csv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]
